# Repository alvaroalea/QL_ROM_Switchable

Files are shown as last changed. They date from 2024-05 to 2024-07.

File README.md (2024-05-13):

# SINCLAIR QL ROM Adapter with up to 8 Banks.

(C) 2024 Alvaro Alea Fernandez

License under: CERN Open Hardware Licence Version 2 - Strongly Reciprocal

https://ohwr.org/cern_ohl_s_v2.txt

MORE INFO WILL BE ADDED, SOON

WARNING: As is design, is to tall (about 3mm) and do not allow the QL Case to be closed. BE AWARE

## Intro

This board consist in 2 part (shall be 3, really)

A board that replace the 2 ROMS of the Sinclair QL. use a 39SF040 (512kb, 8x64kb, same chip that zx spectrum dandanator)

A board that allow to program the EEPROM Chip in a standar chip programmer.

A optional small board to glue in the outside of Sinclair QL (with dual side tape) and allow easy switch of the ROM, this board is not included, because I use a simple breadboard, with a 4 DIP Switch, and 6 cables that go to 5 back pines of the main board, the 4 pins in the border are not used.

## Instructions

Use female, turn-pin socket in the botton of the board, and 6 male pins on the adapter for the 2x3 conector in the middle, check the height of all.

J2 shall have 3 jumper 1-2, 3-4 and 5-6 for normal use, remove the 3 jumpers to program the chip.

J1 pins 1-2 are to enable the top 16Kb of memory, normally with Toolkit II, remove to use the external ROM Cartridge slot (for QIMSI, MICE and others)
J1 pins 3-4,5-6 and 7-8 allow to select between 8 banks of ROM.
Remove all J1 jumpers to program the chip.

Insert the main board into the programer board, and insert both in the programer to program it.

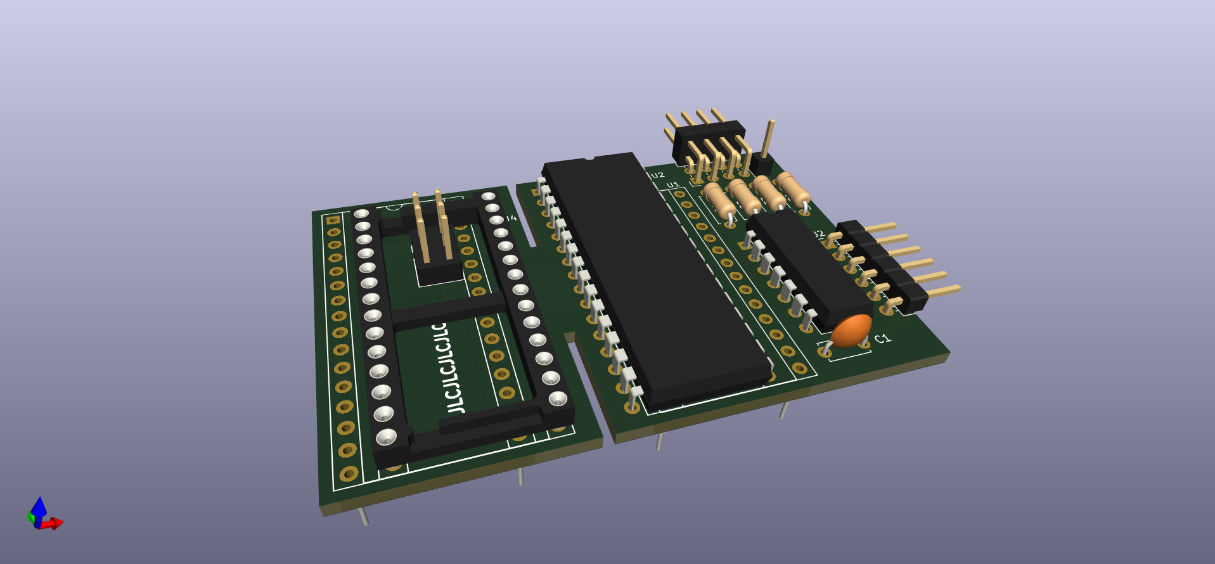
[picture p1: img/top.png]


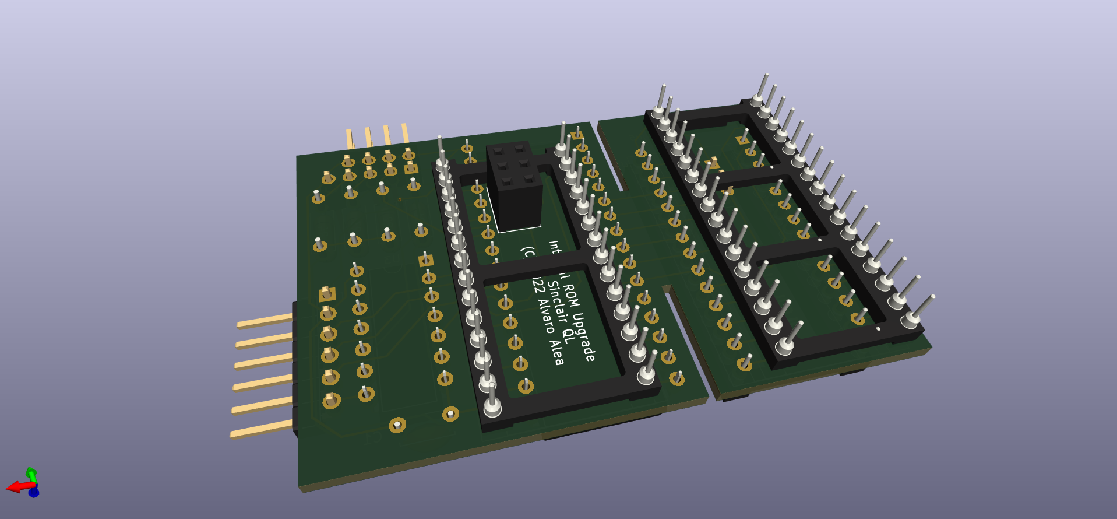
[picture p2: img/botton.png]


## The real thing

The board installed on the QL:

My image

Detail of the switch on back to select the ROM:

My image

The adapter on programmer:

My image

The board in the adapter ready to burn, check the J2 without jumpers.

My image

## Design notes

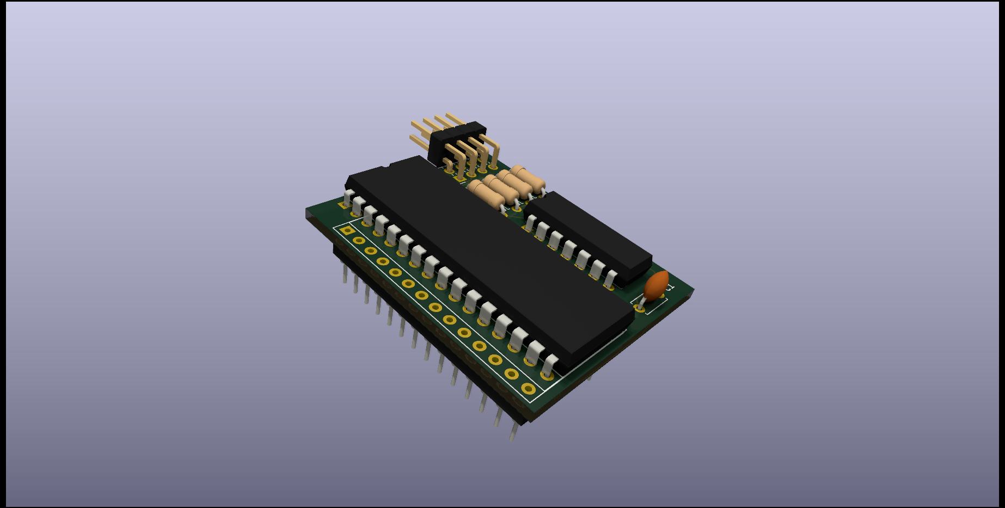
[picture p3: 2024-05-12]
QL_ROM_Switchable.png

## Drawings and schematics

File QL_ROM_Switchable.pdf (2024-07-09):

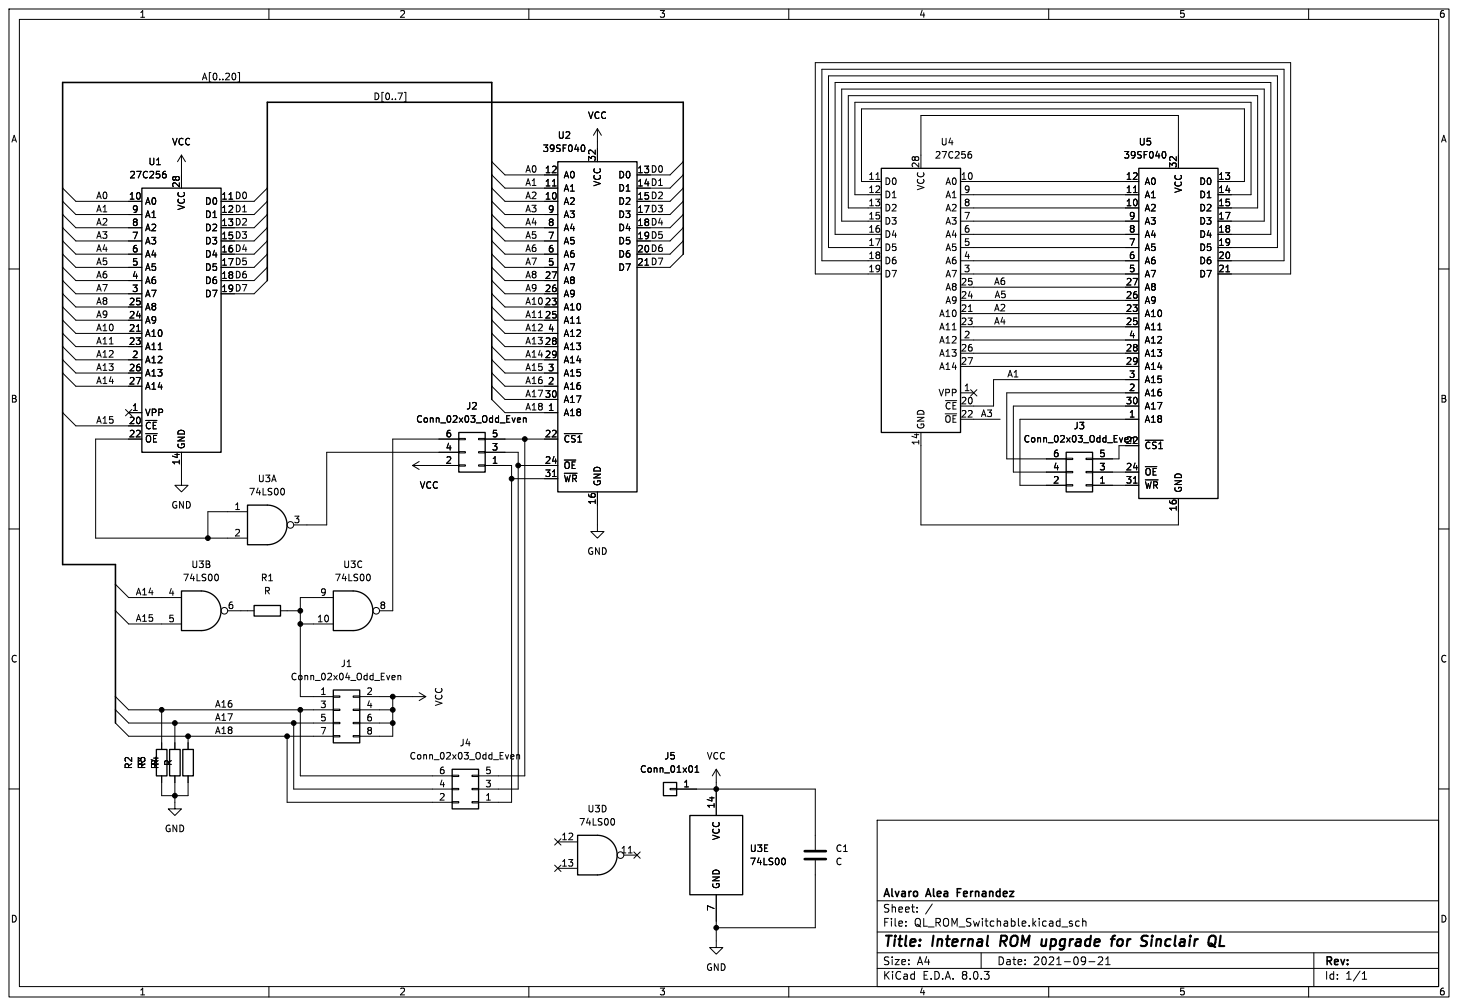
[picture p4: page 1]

Id: 1/1 Title: Internal ROM upgrade for Sinclair QL

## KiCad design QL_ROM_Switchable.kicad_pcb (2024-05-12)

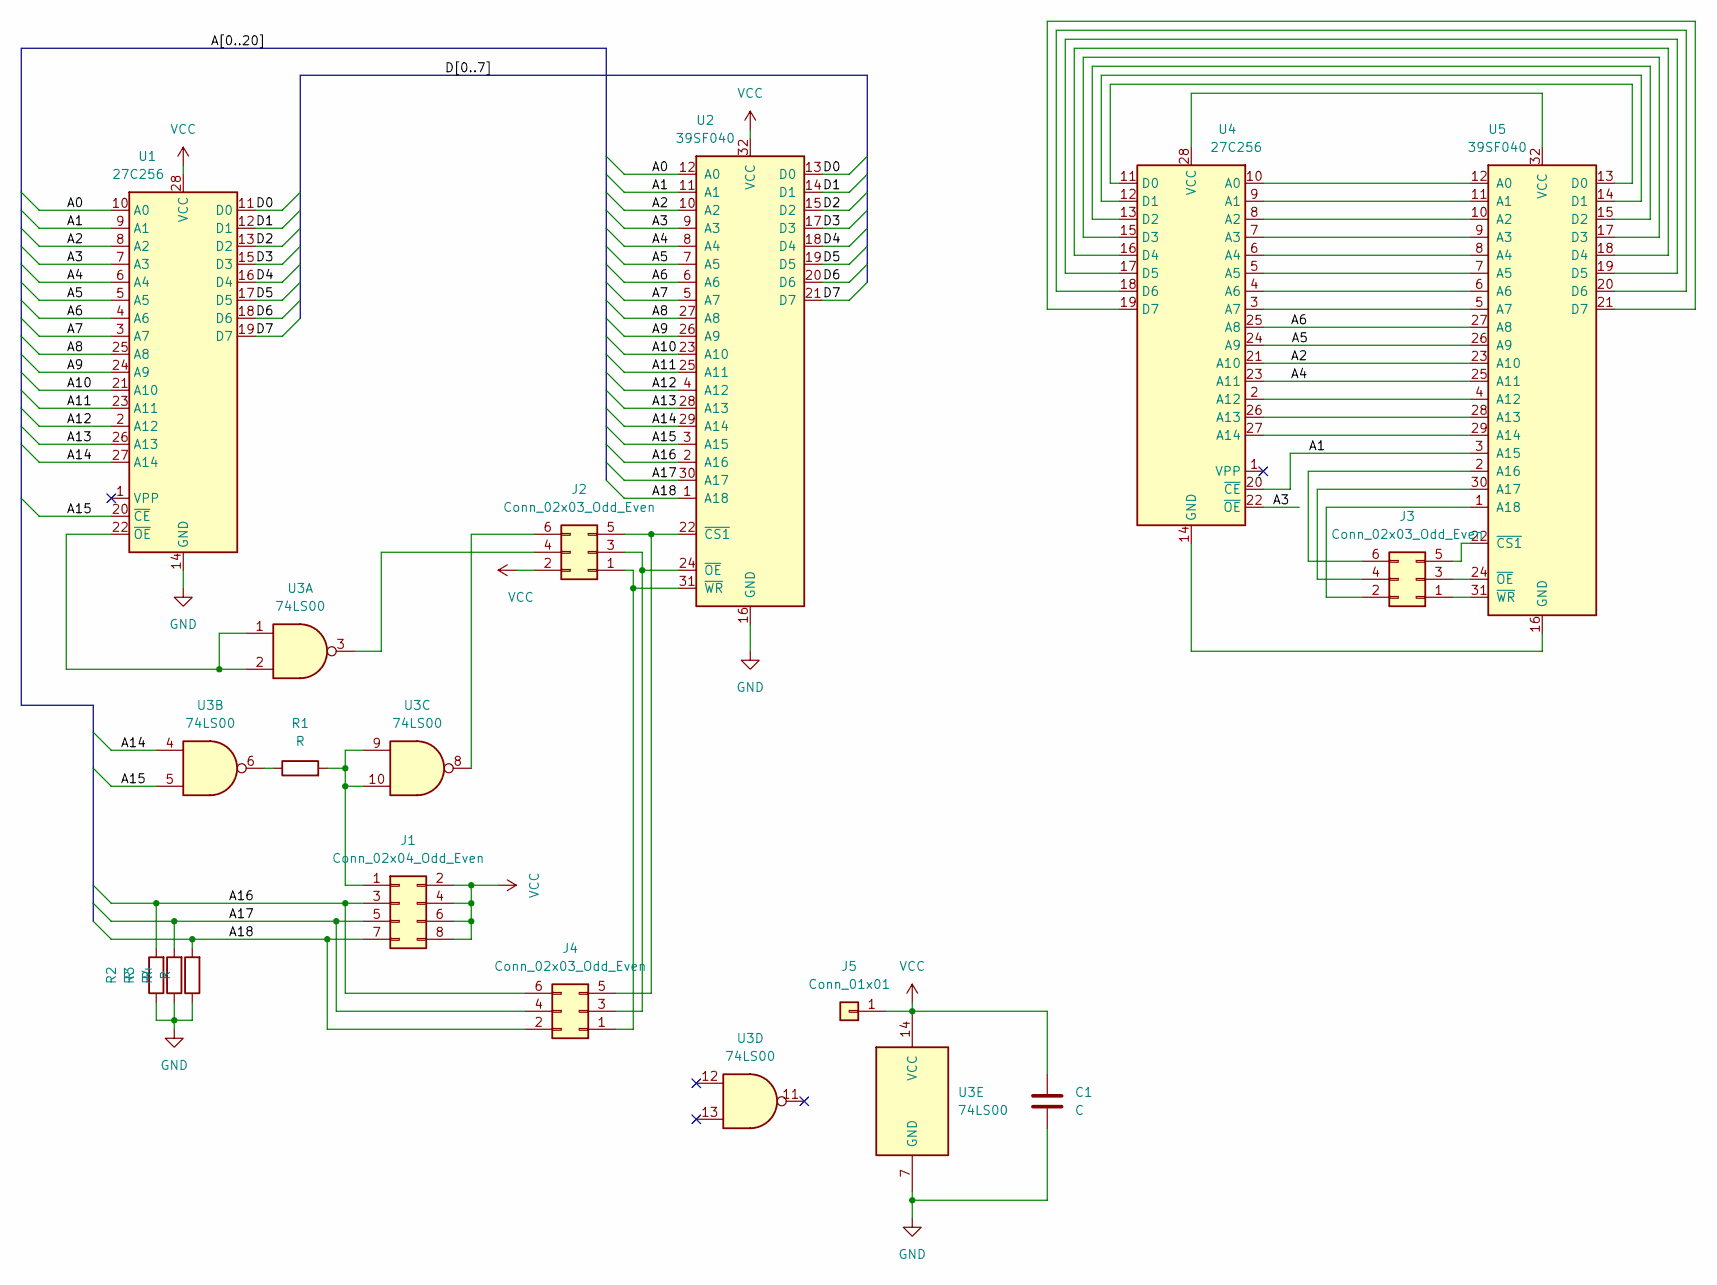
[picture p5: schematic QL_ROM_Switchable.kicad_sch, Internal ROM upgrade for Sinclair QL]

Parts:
C1: C; C_Disc_D5.0mm_W2.5mm_P5.00mm
J1: Conn_02x04_Odd_Even; PinHeader_2x04_P2.54mm_Horizontal
J2: Conn_02x03_Odd_Even; PinHeader_1x06_P2.54mm_Horizontal
J3: Conn_02x03_Odd_Even; PinHeader_2x03_P2.54mm_Vertical
J4: Conn_02x03_Odd_Even; PinSocket_2x03_P2.54mm_Vertical
J5: Conn_01x01; PinHeader_1x01_P2.54mm_Vertical
R1, R2, R3, R4: R; R_Axial_DIN0207_L6.3mm_D2.5mm_P7.62mm_Horizontal
U1, U4: 27C256; DIP-28_W15.24mm_Socket
U2: 39SF040; DIP-32_W15.24mm
U3: 74LS00; DIP-14_W7.62mm
U5: 39SF040; DIP-32_W15.24mm_Socket

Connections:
/A0: U1.10 (A0), U2.12 (A0)
/A1: U1.9 (A1), U2.11 (A1), U4.20 (~CE), U5.3 (A15)
/A2: U1.8 (A2), U2.10 (A2), U4.21 (A10), U5.23 (A10)
/A3: U1.7 (A3), U2.9 (A3), U4.22 (~OE)
/A4: U1.6 (A4), U2.8 (A4), U4.23 (A11), U5.25 (A11)
/A5: U1.5 (A5), U2.7 (A5), U4.24 (A9), U5.26 (A9)
/A6: U1.4 (A6), U2.6 (A6), U4.25 (A8), U5.27 (A8)
/A7: U1.3 (A7), U2.5 (A7)
/A8: U1.25 (A8), U2.27 (A8)
/A9: U1.24 (A9), U2.26 (A9)
/A10: U1.21 (A10), U2.23 (A10)
/A11: U1.23 (A11), U2.25 (A11)
/A12: U1.2 (A12), U2.4 (A12)
/A13: U1.26 (A13), U2.28 (A13)
/A14: U1.27 (A14), U2.29 (A14), U3.4
/A15: U1.20 (~CE), U2.3 (A15), U3.5
/A16: J1.3, J4.6, R2.2, U2.2 (A16)
/A17: J1.5, J4.4, R3.2, U2.30 (A17)
/A18: J1.7, J4.2, R4.2, U2.1 (A18)
/D0: U1.11 (D0), U2.13 (D0)
/D1: U1.12 (D1), U2.14 (D1)
/D2: U1.13 (D2), U2.15 (D2)
/D3: U1.15 (D3), U2.17 (D3)
/D4: U1.16 (D4), U2.18 (D4)
/D5: U1.17 (D5), U2.19 (D5)
/D6: U1.18 (D6), U2.20 (D6)
/D7: U1.19 (D7), U2.21 (D7)
GND: C1.2, R2.1, R3.1, R4.1, U1.14 (GND), U2.16 (GND), U3.7 (GND)
unnamed: J1.1, R1.2, U3.9, U3.10
unnamed: J2.1, J4.1, U2.31 (~WR)
unnamed: J2.3, J4.3, U2.24 (~OE)
unnamed: J2.4, U3.3
unnamed: J2.5, J4.5, U2.22 (~CS1)
unnamed: J2.6, U3.8
unnamed: J3.1, U5.31 (~WR)
unnamed: J3.2, U5.1 (A18)
unnamed: J3.3, U5.24 (~OE)
unnamed: J3.4, U5.30 (A17)
unnamed: J3.5, U5.22 (~CS1)
unnamed: J3.6, U5.2 (A16)
unnamed: R1.1, U3.6
unnamed: U1.22 (~OE), U3.1, U3.2
unnamed: U4.10 (A0), U5.12 (A0)
unnamed: U4.9 (A1), U5.11 (A1)
unnamed: U4.8 (A2), U5.10 (A2)
unnamed: U4.7 (A3), U5.9 (A3)
unnamed: U4.6 (A4), U5.8 (A4)
unnamed: U4.5 (A5), U5.7 (A5)
unnamed: U4.4 (A6), U5.6 (A6)
unnamed: U4.3 (A7), U5.5 (A7)
unnamed: U4.2 (A12), U5.4 (A12)
unnamed: U4.26 (A13), U5.28 (A13)
unnamed: U4.27 (A14), U5.29 (A14)
unnamed: U4.11 (D0), U5.13 (D0)
unnamed: U4.12 (D1), U5.14 (D1)
unnamed: U4.13 (D2), U5.15 (D2)
unnamed: U4.15 (D3), U5.17 (D3)
unnamed: U4.16 (D4), U5.18 (D4)
unnamed: U4.17 (D5), U5.19 (D5)
unnamed: U4.18 (D6), U5.20 (D6)
unnamed: U4.19 (D7), U5.21 (D7)
unnamed: U4.14 (GND), U5.16 (GND)
unnamed: U4.28 (VCC), U5.32 (VCC)
VCC: C1.1, J1.2, J1.4, J1.6, J1.8, J2.2, J5.1, U1.28 (VCC), U2.32 (VCC), U3.14 (VCC)

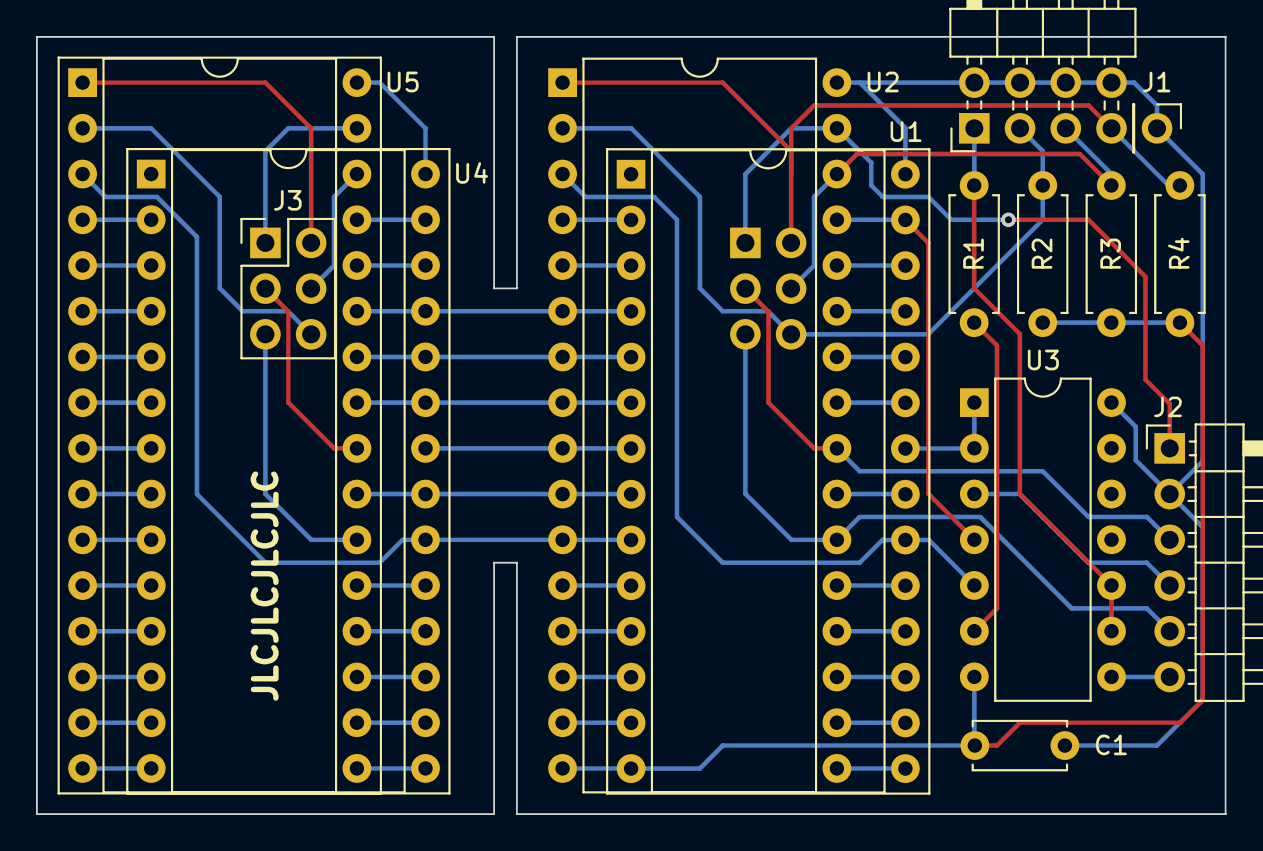
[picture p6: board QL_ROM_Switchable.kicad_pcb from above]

Board: 2 copper layers, 66.0 x 43.2 mm, 15 parts (1 on the bottom side), 64 nets.

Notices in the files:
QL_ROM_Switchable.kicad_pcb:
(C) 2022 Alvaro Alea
